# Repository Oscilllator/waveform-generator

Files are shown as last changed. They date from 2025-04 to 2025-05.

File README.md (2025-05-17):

# Why does it exist

The purpose of this waveform generator is to give your computer the ability to make waves. It should be thought of as a waveform interface for your computer, like a network interface or an audio interface. The computer streams waveforms continuously to the generator, the generator itself has no memory.
I created this because I don't like the software interface to any other waveform generator I have used.

You use it like this:
```python
import numpy as np
import awglib
awg = awglib.awg()
samples = np.sin(np.linspace(0, 2 * np.pi, 1000))
awg.send_volts(samples)
```

You can simply stream samples to it, or gate the sending of the samples on a trigger input. It also has two digital outputs which are embedded in the sample stream. You can use them like this:

```python
samples = np.sin(np.linspace(0, 2 * np.pi, 1000))
d0 = samples > 0.8
d1 = samples < -0.5
awg.send_volts(samples, digital=[d0, d1])
```

Which then would look like this:
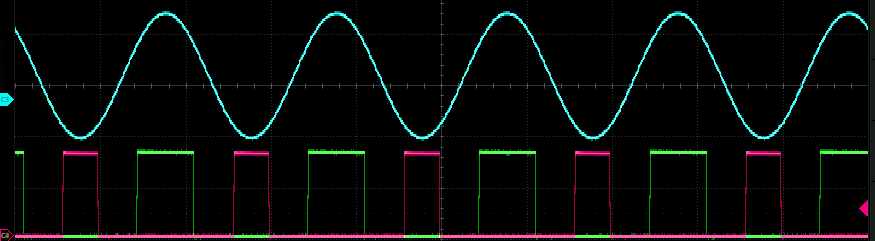
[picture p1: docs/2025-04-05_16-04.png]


This is useful for triggering your scope or other instruments.

## Specifications
| Parameter | Value |
|---|---|
| Samples rate | 10 MSa/s |
| Rise/fall time | 50 ns |
| Max output current  | 600 mA |
| Resolution | 14 bit |
| Digital outputs | 2 |

The device also has a 16 bit digital output bus for debugging the fpga, and 8 LED's. The digital outputs come straight from the FPGA and so have no drive strength to speak of. You won't blow up the FPGA if you 50R terminate them, though.

It looks like this:

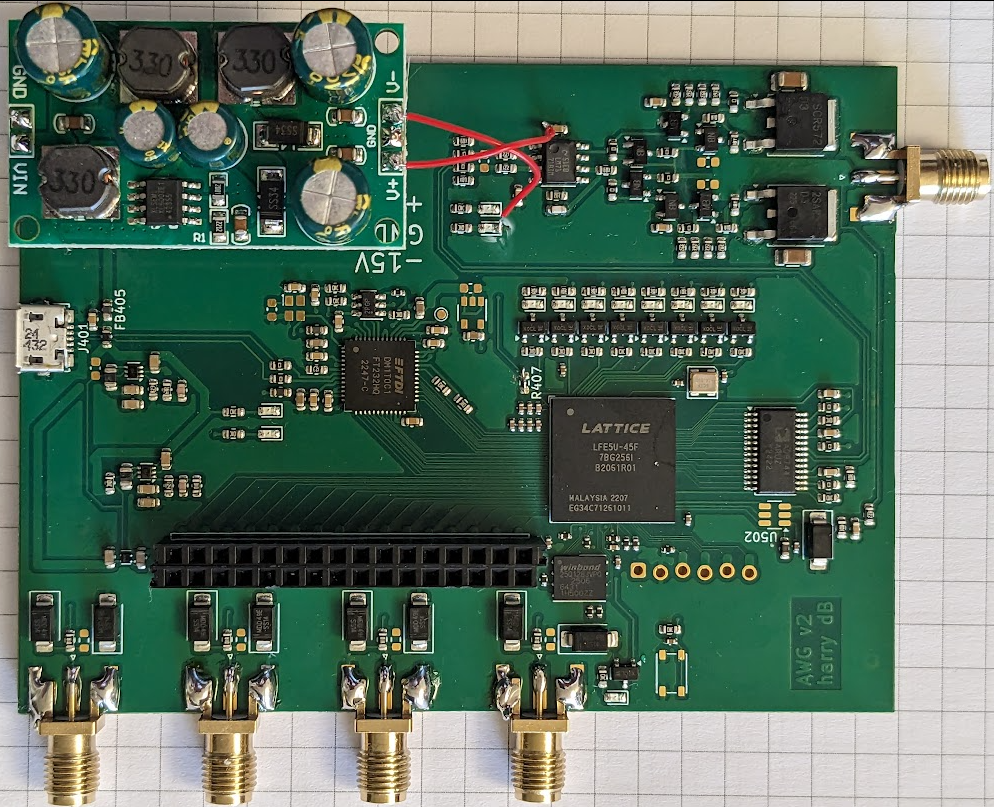
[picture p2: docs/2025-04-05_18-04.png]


## Examples

### Scrolling text

This example is `examples/scrolling_text.py` and demonstrates some of the benefits of having a streaming setup - there is a lot of memory on your main computer as compared to any reasonable waveform generator.

This whole gif is one single waveform of about ~500MB over the wire. Several passes are made over the text, one for each letter section. The persistence of vision within the oscilloscope stitches them together, producing whole letters. Once the whole text has been emitted the waveform is then re-emitted with the embedded digital trigger pulse sent with a slightly different time delay. This is easily done by simply concatenating the waveform to itself many times, attaching a shifted version of the trigger array each time. This wastes a lot of memory but was trivial to implement.

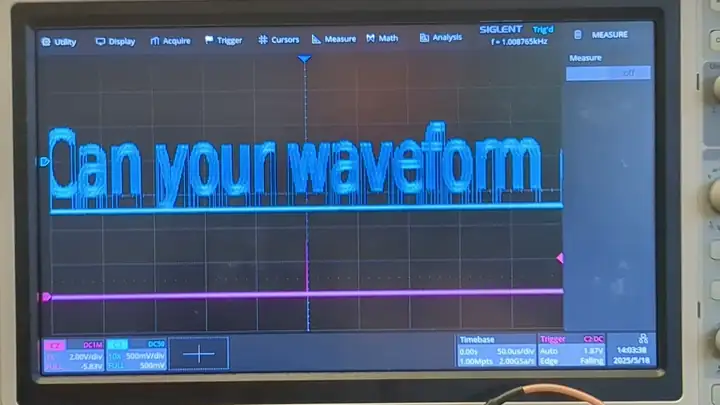
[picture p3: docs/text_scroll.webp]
demo


## Setup
### From a new computer
#### Udev rules
The USB chip is a FT232, but I have programmed it to have a custom Vid and Pid, so that the linux kernel doesn't grab it.

This script sets up the udev rules so the device can be opened without root:

```./ft/setup.sh```
#### Python library
I install it like this from the root directory of the repository:

```pip install -e .```

That way the library is loaded from the repository on startup rather than being copied to an install directory. Ask your favourite AI what's right for you.

### From a bare PCB
The EEPROM of the FT2332 needs to be programmed so that it will output in synchronous FIFO mode, and so that the default vendor ID and product ID is changed, preventing the linux kernel from recognising it.

```./program_eeprom.sh```

## Repository contents
This repository contains the kicad files, RTL, and API to operate a waveform generator.

### Hardware
I got the PCB's assembled with JLCPCB's 6 layer service with plated over vias, to make the routing of the FPGA BGA package easy.
The device uses an FT232 as a USB->FIFO adapter, that currently streams exclusively in the PC->FT232 direction. Use of the device in this mode requires flashing the eeprom, for which a utility is also included.

### RTL
The Flow of information is as follows:

PC -> FT232 -> ECP5 FPGA -> AD9744 DAC -> Amplifier

The RTL for the fpga is provided, which uses the excellent repository [here](https://github.com/WangXuan95/FPGA-ftdi245fifo/tree/main?tab=readme-ov-file#cn) to interface with the FT232. The AD9744 has a simple parallel interface, so that also makes things easy.

The simulation can be run as a unit test with `./run_tests.sh`

### API
The waveform generator is interfaces with in python, though I may [port it to C](https://harrydb.com/Continuous-waveforms) at some point.

### Bringup notes

This device was designed as a series of sub-boards. It started as a [Colorlight DAC](https://harrydb.com/20240902-A-good-waveform-generator) dev board and the [amplifier stage](https://harrydb.com/20250103-awg-buffer-bringup). These were then merged into a [Single PCB](https://harrydb.com/20250403-AWG-2-bringup). There are [various other notes](https://harrydb.com/#waveform-generator) on my lab notes page that detail other parts of the design process.

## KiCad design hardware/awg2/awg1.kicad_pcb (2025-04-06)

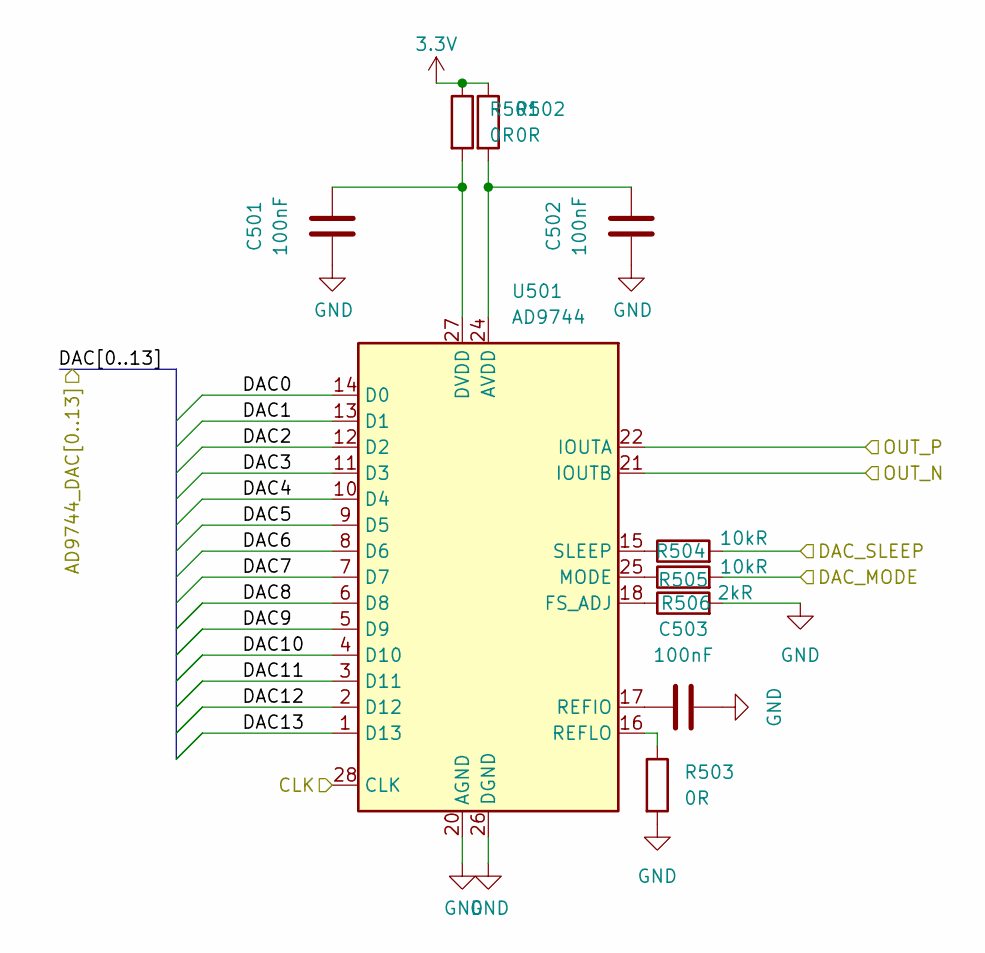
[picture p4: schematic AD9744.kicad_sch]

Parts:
C501, C502, C503: 100nF; R_0603_1608Metric; LCSC C1634
R501, R502: 0R; R_0603_1608Metric
R503: 0R; R_0603_1608Metric; LCSC C22787
R504, R505: 10kR; R_0603_1608Metric; LCSC C22787
R506: 2kR; R_0603_1608Metric; LCSC C22787
U501: AD9744; TSSOP-28_4.4x9.7mm_P0.65mm

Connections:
3.3V: R501.1, R502.1; also elsewhere on the board
/AD9744/CLK: U501.28 (CLK); also elsewhere on the board
/AD9744/DAC0: U501.14 (D0); also elsewhere on the board
/AD9744/DAC1: U501.13 (D1); also elsewhere on the board
/AD9744/DAC2: U501.12 (D2); also elsewhere on the board
/AD9744/DAC3: U501.11 (D3); also elsewhere on the board
/AD9744/DAC4: U501.10 (D4); also elsewhere on the board
/AD9744/DAC5: U501.9 (D5); also elsewhere on the board
/AD9744/DAC6: U501.8 (D6); also elsewhere on the board
/AD9744/DAC7: U501.7 (D7); also elsewhere on the board
/AD9744/DAC8: U501.6 (D8); also elsewhere on the board
/AD9744/DAC9: U501.5 (D9); also elsewhere on the board
/AD9744/DAC10: U501.4 (D10); also elsewhere on the board
/AD9744/DAC11: U501.3 (D11); also elsewhere on the board
/AD9744/DAC12: U501.2 (D12); also elsewhere on the board
/AD9744/DAC13: U501.1 (D13); also elsewhere on the board
/AD9744/DAC_MODE: R505.2; also elsewhere on the board
/AD9744/DAC_SLEEP: R504.2; also elsewhere on the board
/AD9744/OUT_N: U501.21 (IOUTB); also elsewhere on the board
/AD9744/OUT_P: U501.22 (IOUTA); also elsewhere on the board
GND: C501.1, C502.1, C503.1, R503.2, R506.2, U501.20 (AGND), U501.26 (DGND); also elsewhere on the board
unnamed: C502.2, R502.2, U501.24 (AVDD)
unnamed: C501.2, R501.2, U501.27 (DVDD)
unnamed: R506.1, U501.18 (FS_ADJ)
unnamed: R505.1, U501.25 (MODE)
unnamed: C503.2, U501.17 (REFIO)
unnamed: R503.1, U501.16 (REFLO)
unnamed: R504.1, U501.15 (SLEEP)

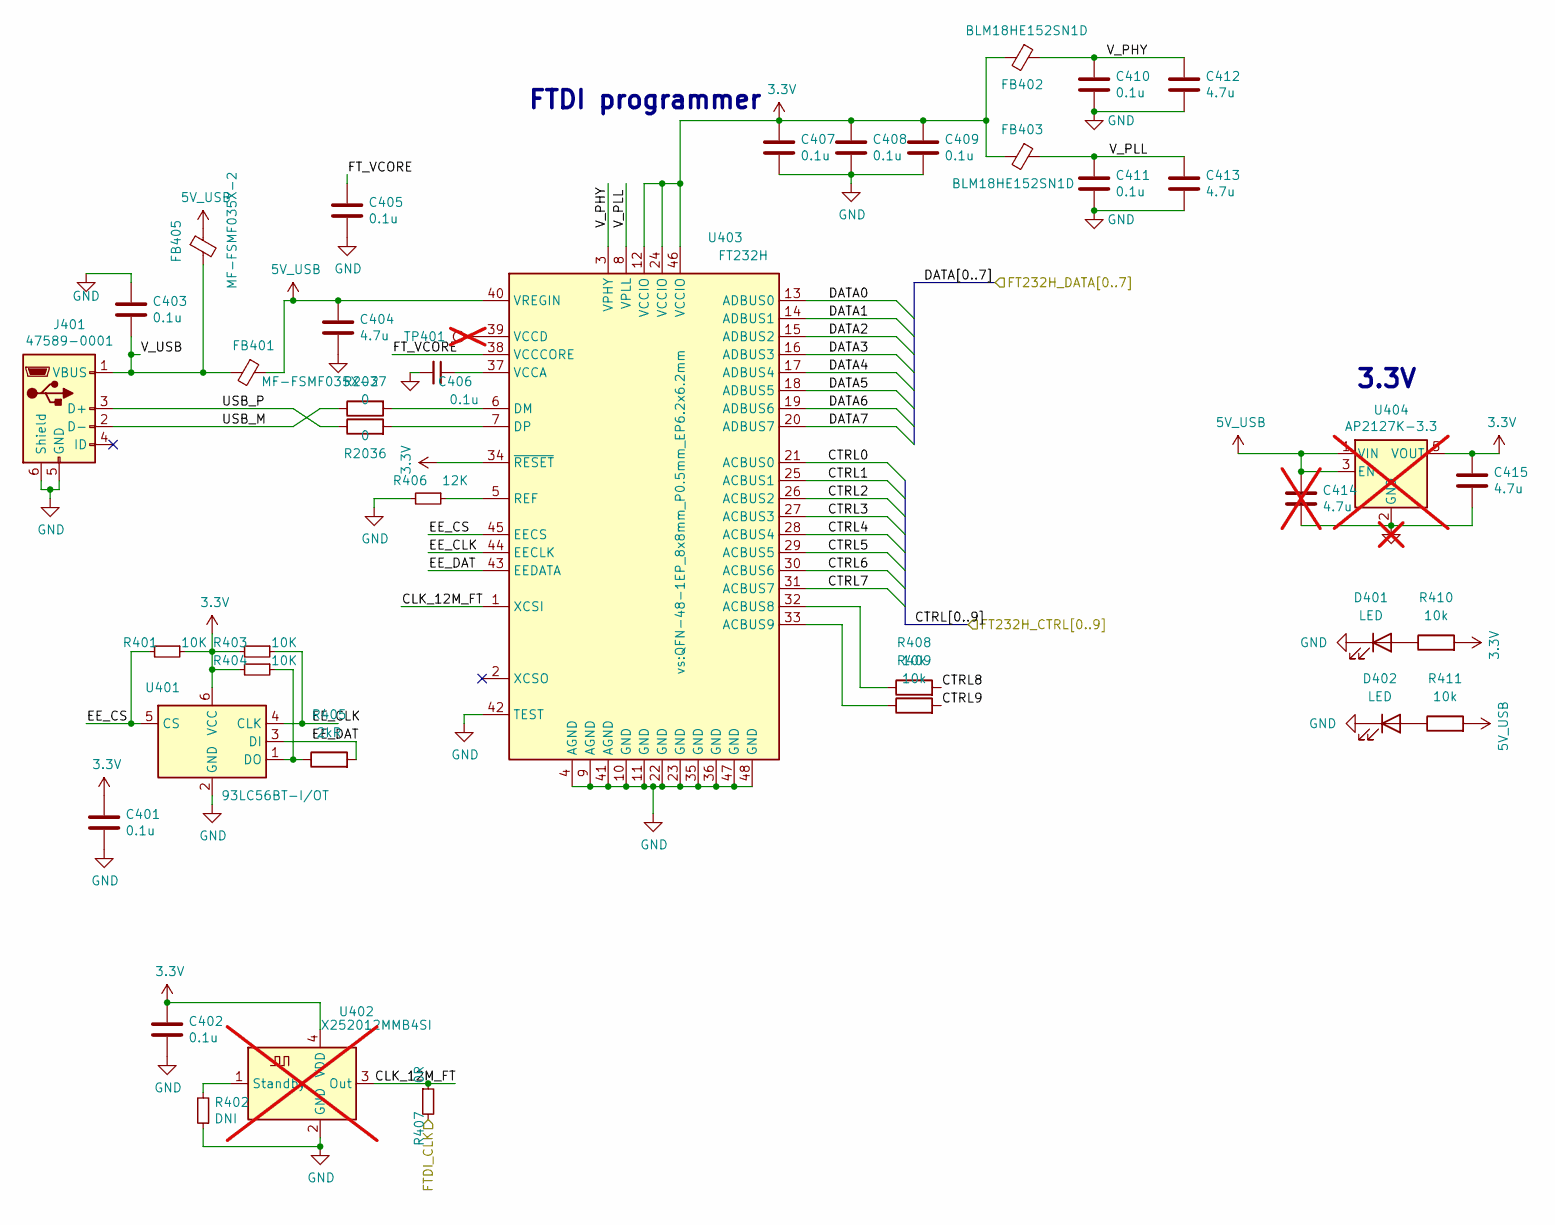
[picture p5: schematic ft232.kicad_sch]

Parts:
C401, C402, C403, C405, C406, C407, C408, C409, C410, C411: 0.1u; C_0603_1608Metric
C404, C412, C413, C415: 4.7u; C_0603_1608Metric
C414: 4.7u; C_0603_1608Metric; not fitted
D401, D402: LED; D_0603_1608Metric; LCSC C2286
FB401, FB405: MF-FSMF035X-2; L_0603_1608Metric
FB402, FB403: BLM18HE152SN1D; L_0603_1608Metric
J401: 47589-0001; USB_Micro-B_Molex_47346-0001
R401, R403, R404: 10K; R_0603_1608Metric
R402: DNI; R_0603_1608Metric
R405: 2kR; R_0402_1005Metric
R406: 12K; R_0603_1608Metric
R407: 0R; R_0603_1608Metric
R408, R409, R410, R411: 10k; R_0603_1608Metric; LCSC C25804
R2036, R2037: 0; R_0603_1608Metric; LCSC C21189
TP401: TestPoint; TestPoint_Pad_D1.0mm; not fitted
U401: 93LC56BT-I/OT; SOT-23-6
U402: X252012MMB4SI; Oscillator_SMD_Abracon_ASDMB-4Pin_2.5x2.0mm; not fitted
U403: FT232H; QFN-48-1EP_8x8mm_P0.5mm_EP6.2x6.2mm
U404: AP2127K-3.3; SOT-23-5; not fitted

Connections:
3.3V: C401.1, C402.1, C407.1, C408.1, C409.1, C415.1, FB402.2, FB403.2, R401.1, R403.2, R404.2, R410.2, U401.6 (VCC), U402.4 (VDD), U403.12 (VCCIO), U403.24 (VCCIO), U403.34 (~RESET), U403.46 (VCCIO), U404.5 (VOUT); also elsewhere on the board
5V_USB: C404.1, C414.1, FB401.1, FB405.1, R411.2, U403.40 (VREGIN), U404.1 (VIN), U404.3 (EN); also elsewhere on the board
/fpga/CTRL0: U403.21 (ACBUS0); also elsewhere on the board
/fpga/CTRL1: U403.25 (ACBUS1); also elsewhere on the board
/fpga/CTRL2: U403.26 (ACBUS2); also elsewhere on the board
/fpga/CTRL3: U403.27 (ACBUS3); also elsewhere on the board
/fpga/CTRL4: U403.28 (ACBUS4); also elsewhere on the board
/fpga/CTRL5: U403.29 (ACBUS5); also elsewhere on the board
/fpga/CTRL6: U403.30 (ACBUS6); also elsewhere on the board
/fpga/CTRL7: U403.31 (ACBUS7); also elsewhere on the board
/fpga/CTRL8: R408.2; also elsewhere on the board
/fpga/CTRL9: R409.2; also elsewhere on the board
/fpga/DATA0: U403.13 (ADBUS0); also elsewhere on the board
/fpga/DATA1: U403.14 (ADBUS1); also elsewhere on the board
/fpga/DATA2: U403.15 (ADBUS2); also elsewhere on the board
/fpga/DATA3: U403.16 (ADBUS3); also elsewhere on the board
/fpga/DATA4: U403.17 (ADBUS4); also elsewhere on the board
/fpga/DATA5: U403.18 (ADBUS5); also elsewhere on the board
/fpga/DATA6: U403.19 (ADBUS6); also elsewhere on the board
/fpga/DATA7: U403.20 (ADBUS7); also elsewhere on the board
/fpga/FTDI_CLK: R407.2; also elsewhere on the board
/ft232/CLK_12M_FT: R407.1, U402.3 (Out), U403.1 (XCSI)
/ft232/EE_CLK: R403.1, U401.4 (CLK), U403.44 (EECLK)
/ft232/EE_CS: R401.2, U401.5 (CS), U403.45 (EECS)
/ft232/EE_DAT: R405.2, U401.3 (DI), U403.43 (EEDATA)
/ft232/FT_VCORE: C405.1, U403.38 (VCCCORE)
/ft232/USB_M: J401.2 (D-), R2036.1
/ft232/USB_P: J401.3 (D+), R2037.1
/ft232/V_PHY: C410.1, C412.1, FB402.1, U403.3 (VPHY)
/ft232/V_PLL: C411.1, C413.1, FB403.1, U403.8 (VPLL)
/ft232/V_USB: C403.2, FB401.2, FB405.2, J401.1 (VBUS)
GND: C401.2, C402.2, C403.1, C404.2, C405.2, C406.2, C407.2, C408.2, C409.2, C410.2, C411.2, C412.2, C413.2, C414.2, C415.2, D401.1 (K), D402.1 (K), J401.5 (GND), J401.6 (Shield), R402.1, R406.2, U401.2 (GND), U402.2 (GND), U403.4 (AGND), U403.9 (AGND), U403.10 (GND), U403.11 (GND), U403.22 (GND), U403.23 (GND), U403.35 (GND), U403.36 (GND), U403.41 (AGND), U403.42 (TEST), U403.47 (GND), U403.48 (GND), U404.2 (GND); also elsewhere on the board
unnamed: D401.2 (A), R410.1
unnamed: D402.2 (A), R411.1
unnamed: R404.1, R405.1, U401.1 (DO)
unnamed: R402.2, U402.1 (Standby)
unnamed: R408.1, U403.32 (ACBUS8)
unnamed: R409.1, U403.33 (ACBUS9)
unnamed: R2036.2, U403.6 (DM)
unnamed: R2037.2, U403.7 (DP)
unnamed: R406.1, U403.5 (REF)
unnamed: C406.1, U403.37 (VCCA)
unnamed: TP401.1, U403.39 (VCCD)

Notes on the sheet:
3.3V
FTDI programmer

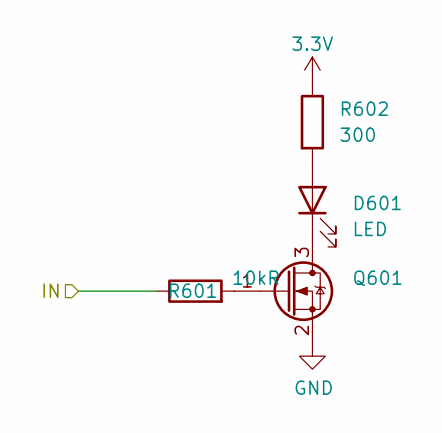
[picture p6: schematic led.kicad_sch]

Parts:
D601: LED; D_0603_1608Metric
Q601: Q_NMOS_Depletion_GSD; SOT-23; LCSC C20917
R601: 10kR; R_0603_1608Metric; LCSC C22787
R602: 300; R_0603_1608Metric_Pad0.98x0.95mm_HandSolder

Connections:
3.3V: R602.1; also elsewhere on the board
/lED0: R601.1; also elsewhere on the board
GND: Q601.2 (S); also elsewhere on the board
unnamed: D601.2 (A), R602.2
unnamed: D601.1 (K), Q601.3 (D)
unnamed: Q601.1 (G), R601.2

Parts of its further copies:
D701, D801, D901, D1001, D1101, D1201, D1301: LED; D_0603_1608Metric
Q701, Q801, Q901, Q1001, Q1101, Q1201, Q1301: Q_NMOS_Depletion_GSD; SOT-23; LCSC C20917
R701, R801, R901, R1001, R1101, R1201, R1301: 10kR; R_0603_1608Metric; LCSC C22787
R702, R802, R902, R1002, R1102, R1202, R1302: 300; R_0603_1608Metric_Pad0.98x0.95mm_HandSolder

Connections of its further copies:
3.3V: R702.1, R802.1, R902.1, R1002.1, R1102.1, R1202.1, R1302.1; also elsewhere on the board
/lED1: R701.1; also elsewhere on the board
/lED2: R801.1; also elsewhere on the board
/lED3: R901.1; also elsewhere on the board
/lED4: R1001.1; also elsewhere on the board
/lED5: R1101.1; also elsewhere on the board
/lED6: R1201.1; also elsewhere on the board
/lED7: R1301.1; also elsewhere on the board
GND: Q701.2 (S), Q801.2 (S), Q901.2 (S), Q1001.2 (S), Q1101.2 (S), Q1201.2 (S), Q1301.2 (S); also elsewhere on the board
unnamed: D701.2 (A), R702.2
unnamed: D701.1 (K), Q701.3 (D)
unnamed: D801.2 (A), R802.2
unnamed: D801.1 (K), Q801.3 (D)
unnamed: D901.2 (A), R902.2
unnamed: D901.1 (K), Q901.3 (D)
unnamed: D1001.2 (A), R1002.2
unnamed: D1001.1 (K), Q1001.3 (D)
unnamed: D1101.2 (A), R1102.2
unnamed: D1101.1 (K), Q1101.3 (D)
unnamed: D1201.2 (A), R1202.2
unnamed: D1201.1 (K), Q1201.3 (D)
unnamed: D1301.2 (A), R1302.2
unnamed: D1301.1 (K), Q1301.3 (D)
unnamed: Q701.1 (G), R701.2
unnamed: Q801.1 (G), R801.2
unnamed: Q901.1 (G), R901.2
unnamed: Q1001.1 (G), R1001.2
unnamed: Q1101.1 (G), R1101.2
unnamed: Q1201.1 (G), R1201.2
unnamed: Q1301.1 (G), R1301.2

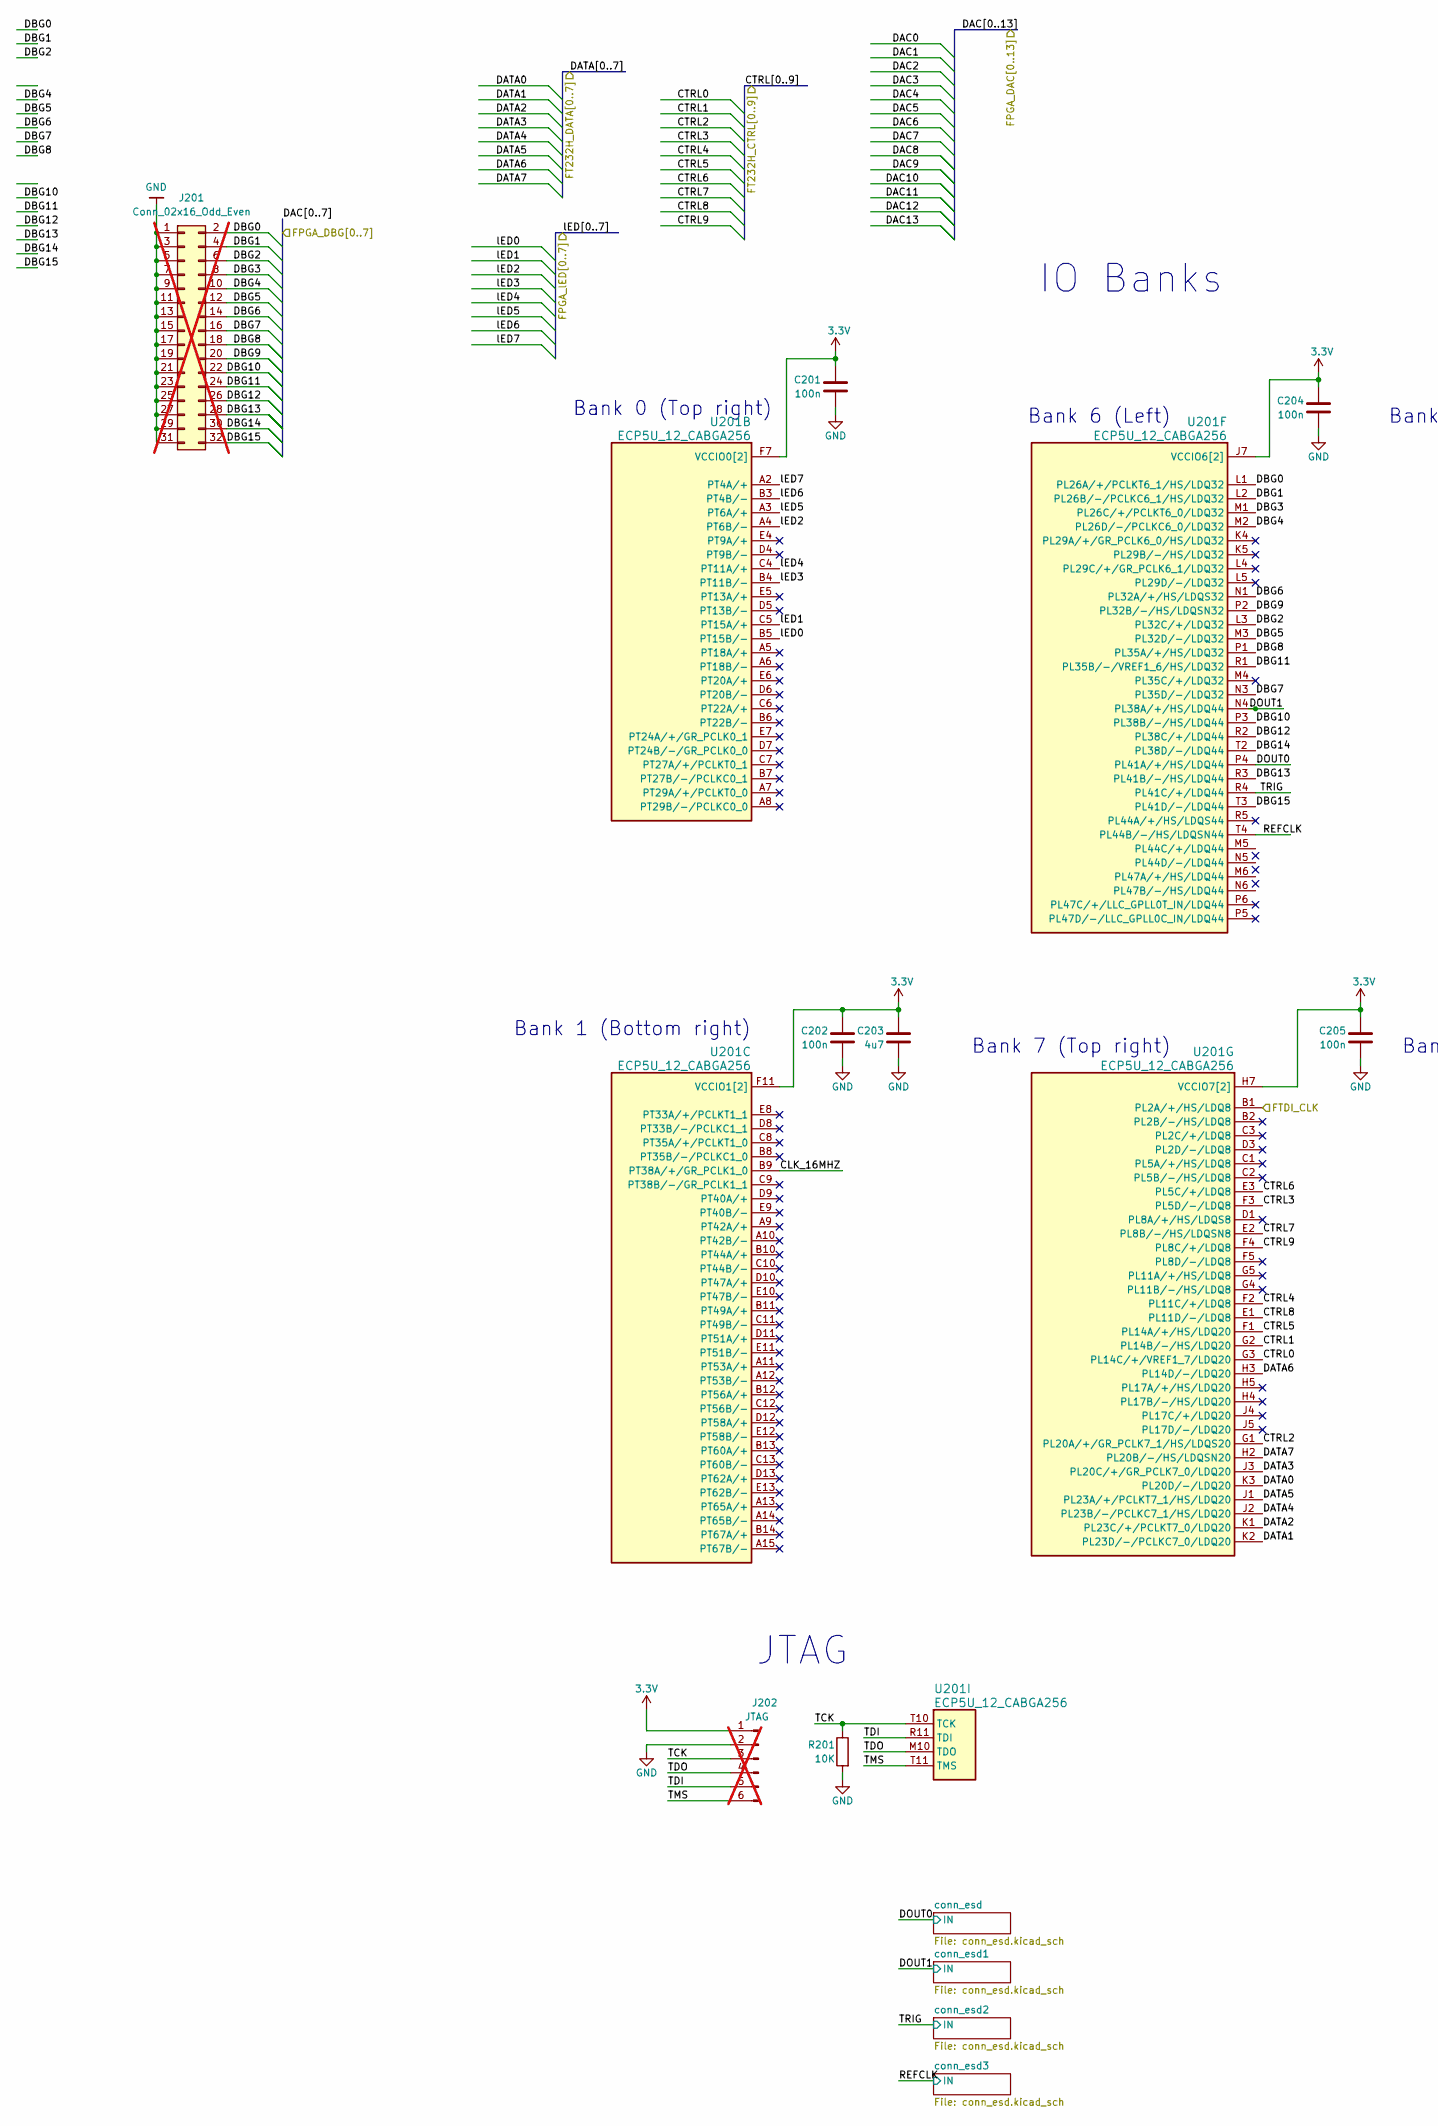
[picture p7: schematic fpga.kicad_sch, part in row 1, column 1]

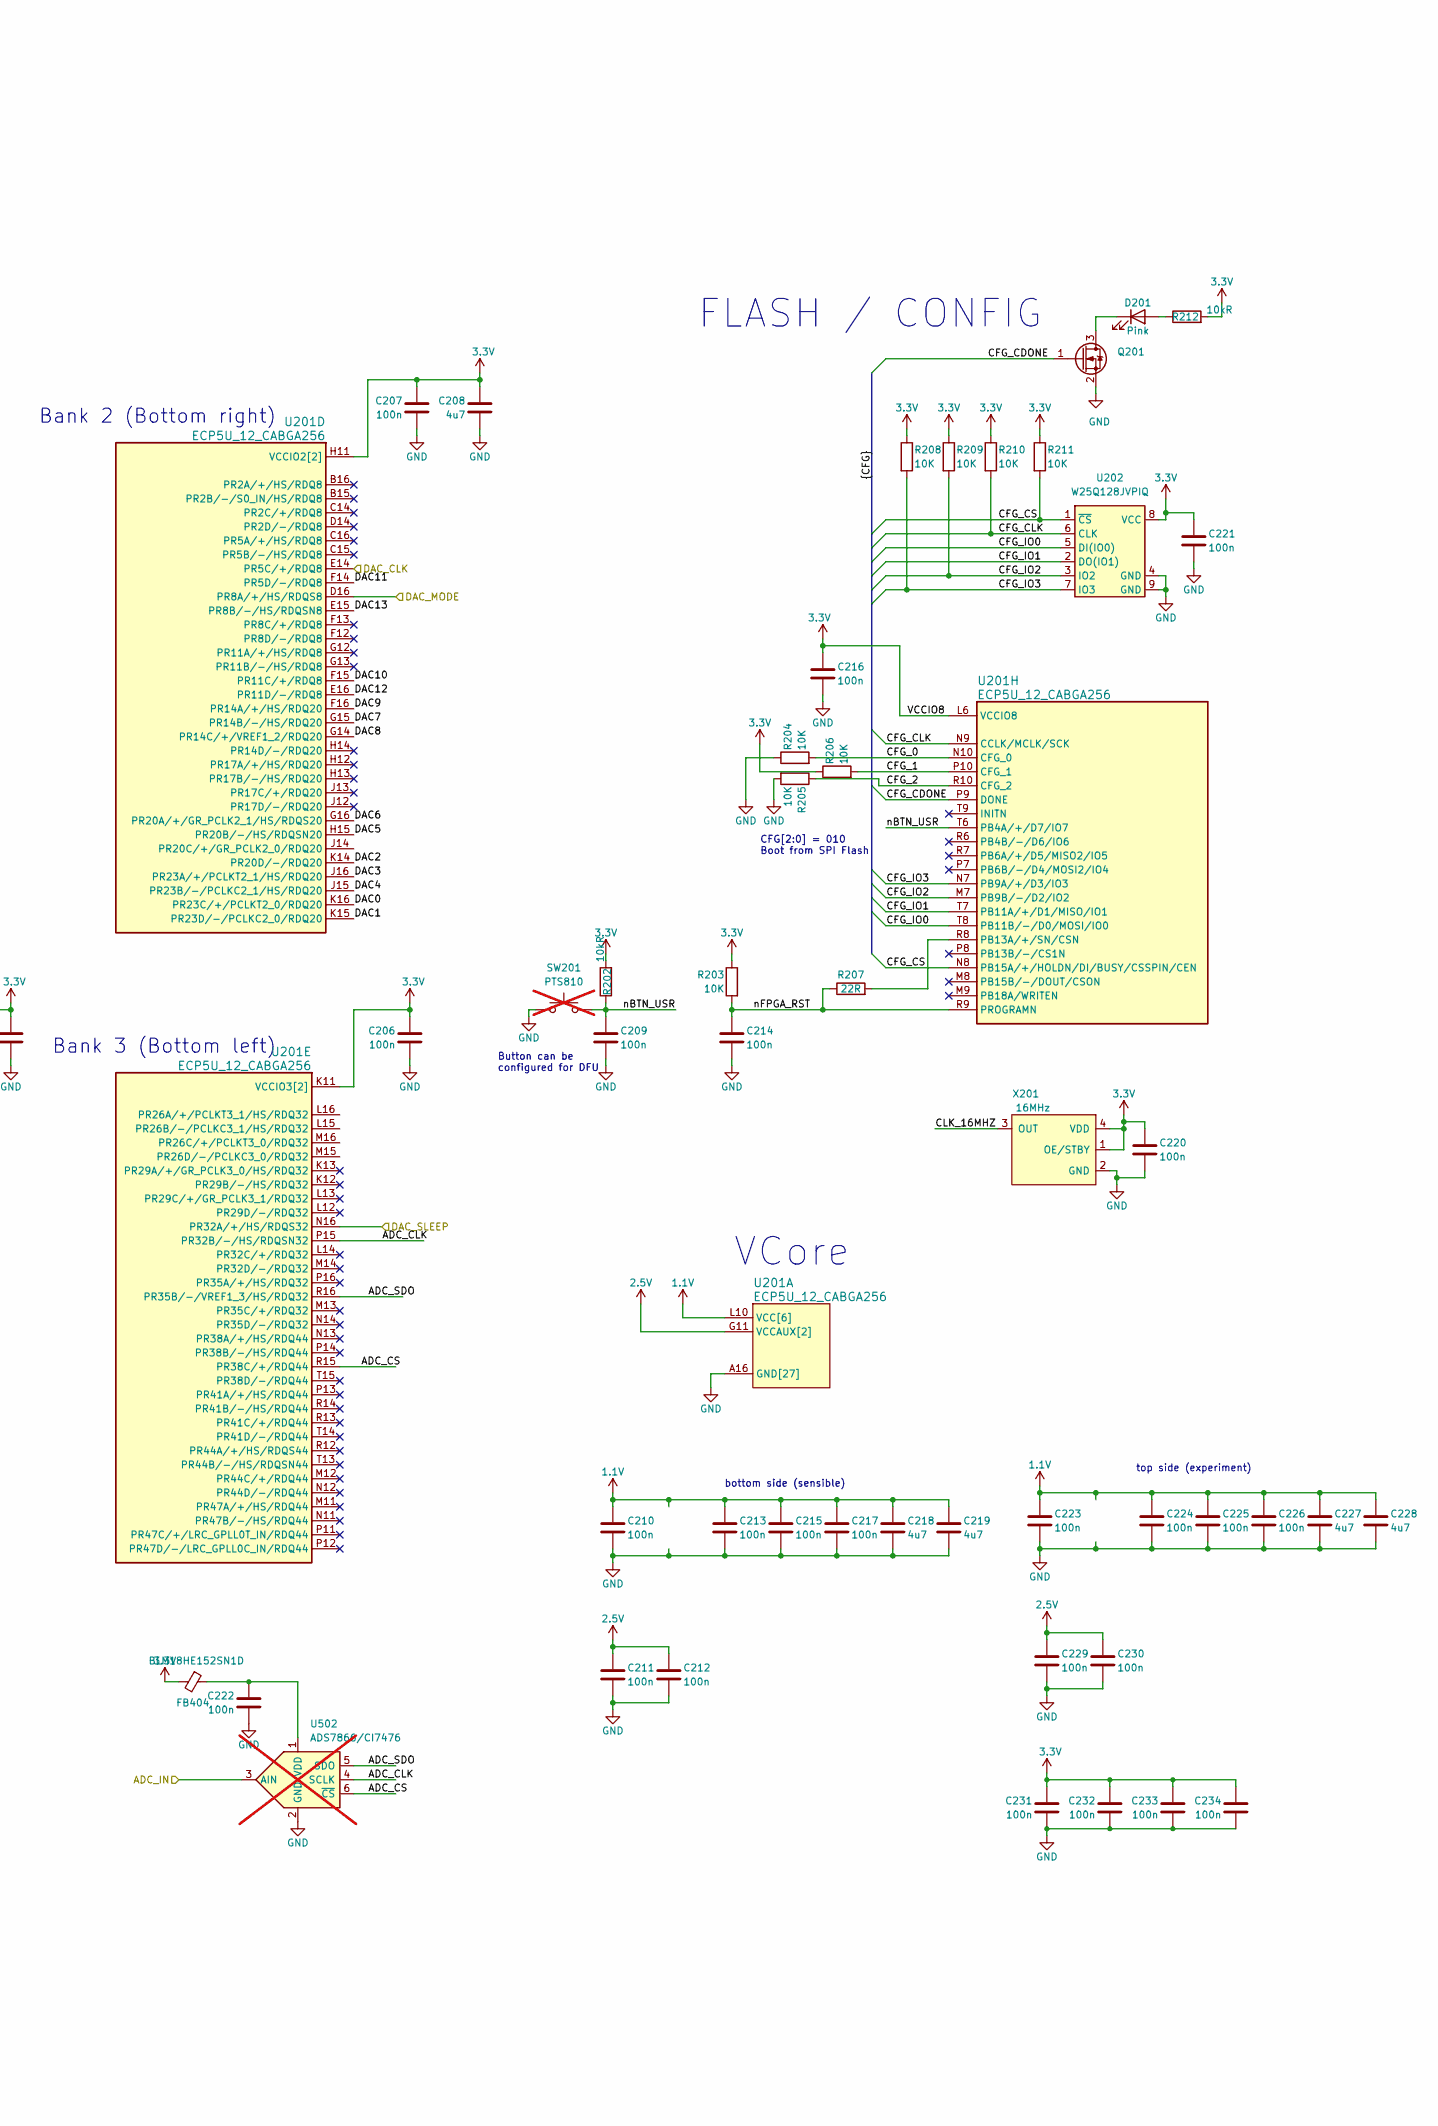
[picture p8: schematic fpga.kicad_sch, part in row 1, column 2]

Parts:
C201, C202, C204, C205, C206, C207, C210, C211, C212, C213, C215, C216, C217, C220, C221, C222, C223, C224, C225, C226, C229, C230, C231, C232, C233, C234: 100n; C_0402_1005Metric; MPN CC0402KRX7R7BB104; LCSC C327009
C203, C208, C218, C219, C227, C228: 4u7; C_0402_1005Metric; MPN CC0402KRX5R6BB475; LCSC C326586
C209, C214: 100n; C_0402_1005Metric; MPN CC0402KRX7R7BB104
D201: Pink; LED_0603_1608Metric; MPN OSK40603C1E; LCSC C268294
FB404: BLM18HE152SN1D; L_0603_1608Metric
J201: Conn_02x16_Odd_Even; PinHeader_2x16_P2.54mm_Vertical; not fitted
J202: JTAG; STM_6_PIN_THT_Staggered; not fitted
Q201: Q_NMOS_Depletion_GSD; SOT-23; LCSC C20917
R201, R203, R204, R205, R206, R208, R209, R210, R211: 10K; R_0402_1005Metric; MPN RC0402JR-0710KL; LCSC C60489
R202, R212: 10kR; R_0603_1608Metric; LCSC C22787
R207: 22R; R_0402_1005Metric; MPN RC0402JR-0722RL
SW201: PTS810; SW_SPST_PTS810; MPN PTS810 SJM 250 SMTR LFS; LCSC C116501; not fitted
U201: ECP5U_12_CABGA256; BGA-256_14.0x14.0mm_Layout16x16_P0.8mm_Ball0.45mm_Pad0.32mm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; MPN LFE5U12F8BG256C
U202: W25Q128JVPIQ; WSON-8-1EP_6x5mm_P1.27mm_EP3.4x4.3mm; MPN W25Q128JVPIQ; LCSC C190862
U502: ADS7866/CI7476; TSOT-23-6; not fitted
X201: 16MHz; CDFN_3.2x2.5mm_XO; MPN DSC6101CI2A-016.0000

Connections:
1.1V: C210.1, C213.1, C215.1, C217.1, C218.1, C219.1, C223.1, C224.1, C225.1, C226.1, C227.1, C228.1, U201.G6 (VCC[6]), U201.G7 (VCC[6]), U201.G9 (VCC[6]), U201.L8 (VCC[6]), U201.L9 (VCC[6]), U201.L10 (VCC[6]); also elsewhere on the board
2.5V: C211.1, C212.1, C229.1, C230.1, U201.G11 (VCCAUX[2]), U201.L7 (VCCAUX[2]); also elsewhere on the board
3.3V: C201.1, C202.1, C203.1, C204.1, C205.1, C206.1, C207.1, C208.1, C216.1, C220.1, C221.1, C231.1, C232.1, C233.1, C234.1, FB404.2, J202.1, R202.2, R203.1, R206.1, R208.1, R209.1, R210.1, R211.1, R212.2, U201.F6 (VCCIO0[2]), U201.F7 (VCCIO0[2]), U201.F10 (VCCIO1[2]), U201.F11 (VCCIO1[2]), U201.H6 (VCCIO7[2]), U201.H7 (VCCIO7[2]), U201.H11 (VCCIO2[2]), U201.J6 (VCCIO6[2]), U201.J7 (VCCIO6[2]), U201.J11 (VCCIO2[2]), U201.K11 (VCCIO3[2]), U201.L6 (VCCIO8), U201.L11 (VCCIO3[2]), U202.8 (VCC), X201.1 (OE/STBY), X201.4 (VDD); also elsewhere on the board
/AD9744/CLK: U201.E14 (PR5C/+/RDQ8); also elsewhere on the board
/AD9744/DAC0: U201.K16 (PR23C/+/PCLKT2_0/RDQ20); also elsewhere on the board
/AD9744/DAC1: U201.K15 (PR23D/-/PCLKC2_0/RDQ20); also elsewhere on the board
/AD9744/DAC2: U201.K14 (PR20D/-/RDQ20); also elsewhere on the board
/AD9744/DAC3: U201.J16 (PR23A/+/PCLKT2_1/HS/RDQ20); also elsewhere on the board
/AD9744/DAC4: U201.J15 (PR23B/-/PCLKC2_1/HS/RDQ20); also elsewhere on the board
/AD9744/DAC5: U201.H15 (PR20B/-/HS/RDQSN20); also elsewhere on the board
/AD9744/DAC6: U201.G16 (PR20A/+/GR_PCLK2_1/HS/RDQS20); also elsewhere on the board
/AD9744/DAC7: U201.G15 (PR14B/-/HS/RDQ20); also elsewhere on the board
/AD9744/DAC8: U201.G14 (PR14C/+/VREF1_2/RDQ20); also elsewhere on the board
/AD9744/DAC9: U201.F16 (PR14A/+/HS/RDQ20); also elsewhere on the board
/AD9744/DAC10: U201.F15 (PR11C/+/RDQ8); also elsewhere on the board
/AD9744/DAC11: U201.F14 (PR5D/-/RDQ8); also elsewhere on the board
/AD9744/DAC12: U201.E16 (PR11D/-/RDQ8); also elsewhere on the board
/AD9744/DAC13: U201.E15 (PR8B/-/HS/RDQSN8); also elsewhere on the board
/AD9744/DAC_MODE: U201.D16 (PR8A/+/HS/RDQS8); also elsewhere on the board
/AD9744/DAC_SLEEP: U201.N16 (PR32A/+/HS/RDQS32); also elsewhere on the board
/awg_amp/OUT_SLOW: U502.3 (AIN); also elsewhere on the board
/fpga/ADC_CLK: U201.P15 (PR32B/-/HS/RDQSN32), U502.4 (SCLK)
/fpga/ADC_CS: U201.R15 (PR38C/+/RDQ44), U502.6 (~CS)
/fpga/ADC_SDO: U201.R16 (PR35B/-/VREF1_3/HS/RDQ32), U502.5 (SDO)
/fpga/CFG_0: R204.2, U201.N10 (CFG_0)
/fpga/CFG_1: R206.2, U201.P10 (CFG_1)
/fpga/CFG_2: R205.1, U201.R10 (CFG_2)
/fpga/CFG_CDONE: Q201.1 (G), U201.P9 (DONE)
/fpga/CFG_CLK: R210.2, U201.N9 (CCLK/MCLK/SCK), U202.6 (CLK)
/fpga/CFG_CS: R211.2, U201.N8 (PB15A/+/HOLDN/DI/BUSY/CSSPIN/CEN), U202.1 (~CS)
/fpga/CFG_IO0: U201.T8 (PB11B/-/D0/MOSI/IO0), U202.5 (DI(IO0))
/fpga/CFG_IO1: U201.T7 (PB11A/+/D1/MISO/IO1), U202.2 (DO(IO1))
/fpga/CFG_IO2: R209.2, U201.M7 (PB9B/-/D2/IO2), U202.3 (IO2)
/fpga/CFG_IO3: R208.2, U201.N7 (PB9A/+/D3/IO3), U202.7 (IO3)
/fpga/CLK_16MHZ: U201.B9 (PT38A/+/GR_PCLK1_0), X201.3 (OUT)
/fpga/CTRL0: U201.G3 (PL14C/+/VREF1_7/LDQ20); also elsewhere on the board
/fpga/CTRL1: U201.G2 (PL14B/-/HS/LDQ20); also elsewhere on the board
/fpga/CTRL2: U201.G1 (PL20A/+/GR_PCLK7_1/HS/LDQS20); also elsewhere on the board
/fpga/CTRL3: U201.F3 (PL5D/-/LDQ8); also elsewhere on the board
/fpga/CTRL4: U201.F2 (PL11C/+/LDQ8); also elsewhere on the board
/fpga/CTRL5: U201.F1 (PL14A/+/HS/LDQ20); also elsewhere on the board
/fpga/CTRL6: U201.E3 (PL5C/+/LDQ8); also elsewhere on the board
/fpga/CTRL7: U201.E2 (PL8B/-/HS/LDQSN8); also elsewhere on the board
/fpga/CTRL8: U201.E1 (PL11D/-/LDQ8); also elsewhere on the board
/fpga/CTRL9: U201.F4 (PL8C/+/LDQ8); also elsewhere on the board
/fpga/DATA0: U201.K3 (PL20D/-/LDQ20); also elsewhere on the board
/fpga/DATA1: U201.K2 (PL23D/-/PCLKC7_0/LDQ20); also elsewhere on the board
/fpga/DATA2: U201.K1 (PL23C/+/PCLKT7_0/LDQ20); also elsewhere on the board
/fpga/DATA3: U201.J3 (PL20C/+/GR_PCLK7_0/LDQ20); also elsewhere on the board
/fpga/DATA4: U201.J2 (PL23B/-/PCLKC7_1/HS/LDQ20); also elsewhere on the board
/fpga/DATA5: U201.J1 (PL23A/+/PCLKT7_1/HS/LDQ20); also elsewhere on the board
/fpga/DATA6: U201.H3 (PL14D/-/LDQ20); also elsewhere on the board
/fpga/DATA7: U201.H2 (PL20B/-/HS/LDQSN20); also elsewhere on the board
/fpga/DBG0: J201.2, U201.L1 (PL26A/+/PCLKT6_1/HS/LDQ32)
/fpga/DBG1: J201.4, U201.L2 (PL26B/-/PCLKC6_1/HS/LDQ32)
/fpga/DBG2: J201.6, U201.L3 (PL32C/+/LDQ32)
/fpga/DBG3: J201.8, U201.M1 (PL26C/+/PCLKT6_0/LDQ32)
/fpga/DBG4: J201.10, U201.M2 (PL26D/-/PCLKC6_0/LDQ32)
/fpga/DBG5: J201.12, U201.M3 (PL32D/-/LDQ32)
/fpga/DBG6: J201.14, U201.N1 (PL32A/+/HS/LDQS32)
/fpga/DBG7: J201.16, U201.N3 (PL35D/-/LDQ32)
/fpga/DBG8: J201.18, U201.P1 (PL35A/+/HS/LDQ32)
/fpga/DBG9: J201.20, U201.P2 (PL32B/-/HS/LDQSN32)
/fpga/DBG10: J201.22, U201.P3 (PL38B/-/HS/LDQ44)
/fpga/DBG11: J201.24, U201.R1 (PL35B/-/VREF1_6/HS/LDQ32)
/fpga/DBG12: J201.26, U201.R2 (PL38C/+/LDQ44)
/fpga/DBG13: J201.28, U201.R3 (PL41B/-/HS/LDQ44)
/fpga/DBG14: J201.30, U201.T2 (PL38D/-/LDQ44)
/fpga/DBG15: J201.32, U201.T3 (PL41D/-/LDQ44)
/fpga/DOUT0: U201.P4 (PL41A/+/HS/LDQ44); also elsewhere on the board
/fpga/DOUT1: U201.N4 (PL38A/+/HS/LDQ44); also elsewhere on the board
/fpga/FTDI_CLK: U201.B1 (PL2A/+/HS/LDQ8); also elsewhere on the board
/fpga/REFCLK: U201.T4 (PL44B/-/HS/LDQSN44); also elsewhere on the board
/fpga/TCK: J202.3, R201.1, U201.T10 (TCK)
/fpga/TDI: J202.5, U201.R11 (TDI)
/fpga/TDO: J202.4, U201.M10 (TDO)
/fpga/TMS: J202.6, U201.T11 (TMS)
/fpga/TRIG: U201.R4 (PL41C/+/LDQ44); also elsewhere on the board
/fpga/nBTN_USR: C209.1, R202.1, SW201.2, U201.T6 (PB4A/+/D7/IO7)
/fpga/nFPGA_RST: C214.1, R203.2, R207.1, U201.R9 (PROGRAMN)
/lED0: U201.B5 (PT15B/-); also elsewhere on the board
/lED1: U201.C5 (PT15A/+); also elsewhere on the board
/lED2: U201.A4 (PT6B/-); also elsewhere on the board
/lED3: U201.B4 (PT11B/-); also elsewhere on the board
/lED4: U201.C4 (PT11A/+); also elsewhere on the board
/lED5: U201.A3 (PT6A/+); also elsewhere on the board
/lED6: U201.B3 (PT4B/-); also elsewhere on the board
/lED7: U201.A2 (PT4A/+); also elsewhere on the board
GND: C201.2, C202.2, C203.2, C204.2, C205.2, C206.2, C207.2, C208.2, C209.2, C210.2, C211.2, C212.2, C213.2, C214.2, C215.2, C216.2, C217.2, C218.2, C219.2, C220.2, C221.2, C222.2, C223.2, C224.2, C225.2, C226.2, C227.2, C228.2, C229.2, C230.2, C231.2, C232.2, C233.2, C234.2, J201.1, J201.3, J201.5, J201.7, J201.9, J201.11, J201.13, J201.15, J201.17, J201.19, J201.21, J201.23, J201.25, J201.27, J201.29, J201.31, J202.2, Q201.2 (S), R201.2, R204.1, R205.2, SW201.1, U201.A1 (GND[27]), U201.A16 (GND[27]), U201.D2 (GND[27]), U201.D15 (GND[27]), U201.F8 (GND[27]), U201.F9 (GND[27]), U201.G8 (GND[27]), U201.G10 (GND[27]), U201.H1 (GND[27]), U201.H8 (GND[27]), U201.H9 (GND[27]), U201.H10 (GND[27]), U201.H16 (GND[27]), U201.J8 (GND[27]), U201.J9 (GND[27]), U201.J10 (GND[27]), U201.K6 (GND[27]), U201.K7 (GND[27]), U201.K8 (GND[27]), U201.K9 (GND[27]), U201.K10 (GND[27]), U201.N2 (GND[27]), U201.N15 (GND[27]), U201.T1 (GND[27]), U201.T5 (GND[27]), U201.T12 (GND[27]), U201.T16 (GND[27]), U202.4 (GND), U202.9 (GND), U502.2 (GND), X201.2 (GND); also elsewhere on the board
unnamed: D201.2 (A), R212.1
unnamed: D201.1 (K), Q201.3 (D)
unnamed: R207.2, U201.R8 (PB13A/+/SN/CSN)
unnamed: C222.1, FB404.1, U502.1 (VDD)

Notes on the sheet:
CFG[2:0] = 010 Boot from SPI Flash
Bank 0 (Top right)
bottom side (sensible)
VCore
top side (experiment)
FLASH / CONFIG
JTAG
Bank 2 (Bottom right)
IO Banks
Bank 1 (Bottom right)
Bank 7 (Top right)
Button can be configured for DFU
Bank 3 (Bottom left)
Bank 6 (Left)

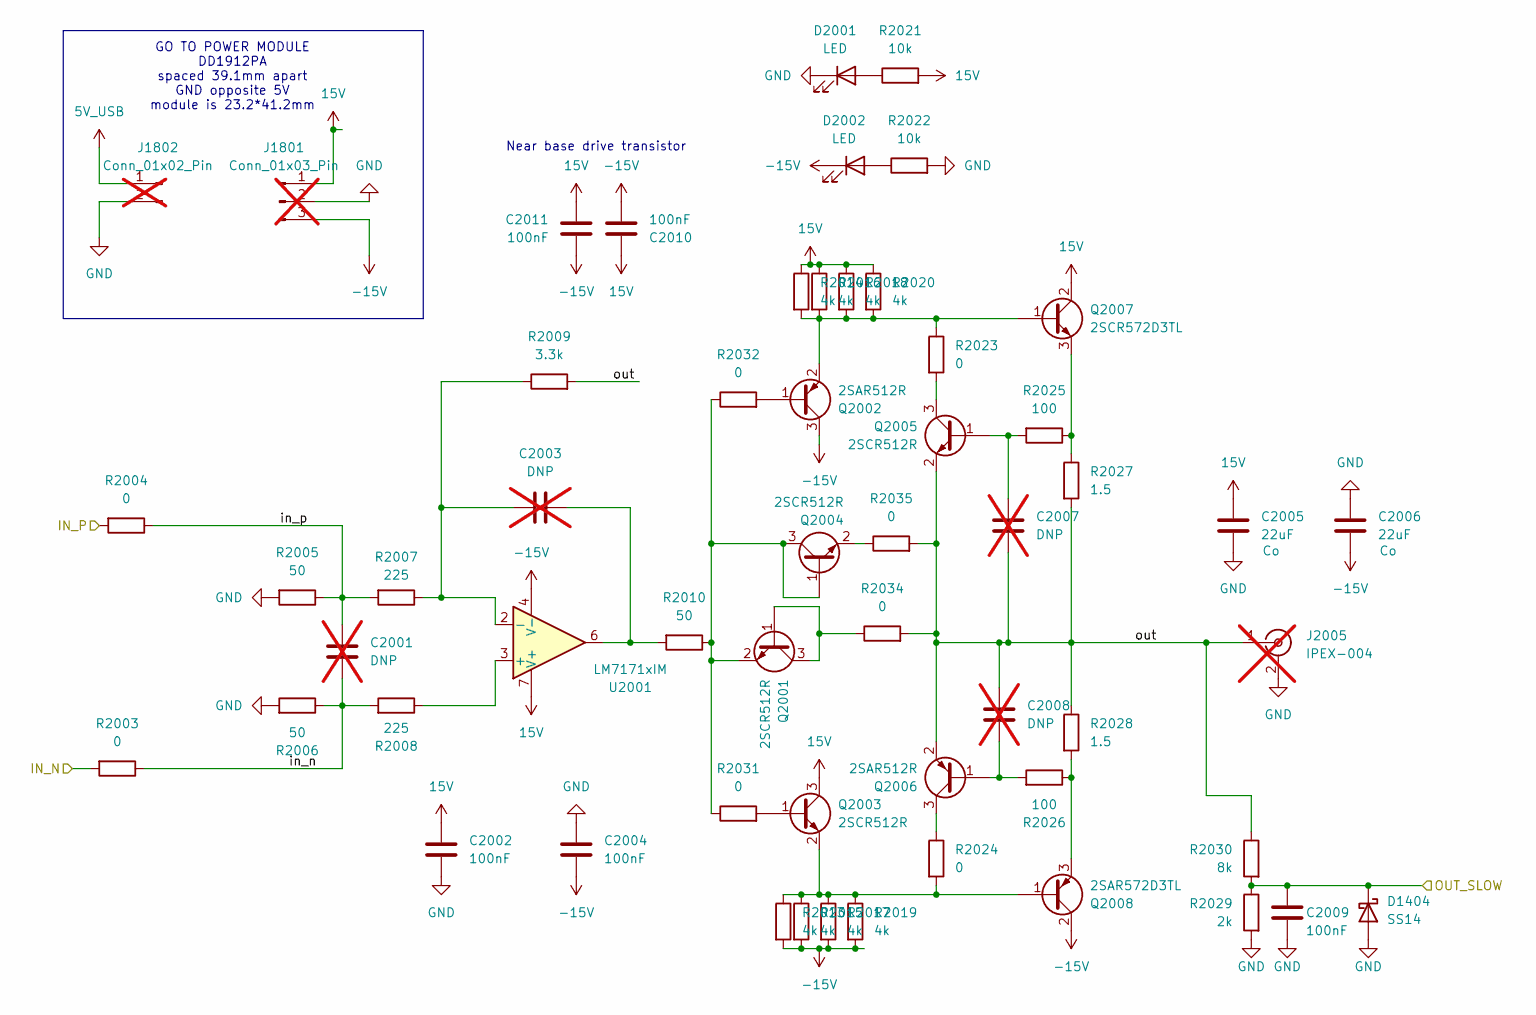
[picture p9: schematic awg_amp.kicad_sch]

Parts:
C2001: DNP; C_0603_1608Metric; LCSC C21120; not fitted
C2002, C2004, C2009, C2010, C2011: 100nF; C_0603_1608Metric; LCSC C1634
C2003, C2007, C2008: DNP; C_0603_1608Metric; LCSC C1634; not fitted
C2005, C2006: 22uF; C_1206_3216Metric
D1404: SS14; D_SMA
D2001, D2002: LED; D_0603_1608Metric; LCSC C2286
J1801: Conn_01x03_Pin; PinHeader_1x03_P2.54mm_Vertical; not fitted
J1802: Conn_01x02_Pin; PinHeader_1x02_P2.54mm_Vertical; not fitted
J2005: IPEX-004; SMA_Amphenol_132289_EdgeMount; not fitted
Q2001, Q2003, Q2004, Q2005: 2SCR512R; SOT-23
Q2002, Q2006: 2SAR512R; SOT-23
Q2007: 2SCR572D3TL; TO-252-2
Q2008: 2SAR572D3TL; TO-252-2
R2003, R2004, R2023, R2024, R2031, R2032, R2034, R2035: 0; R_0603_1608Metric; LCSC C21189
R2005, R2006, R2010: 50; R_0603_1608Metric; LCSC C23185
R2007, R2008: 225; R_0603_1608Metric; LCSC C22962
R2009: 3.3k; R_0603_1608Metric; LCSC C22975
R2013, R2014, R2015, R2016, R2017, R2018, R2019, R2020: 4k; R_0603_1608Metric; LCSC C23138
R2021, R2022: 10k; R_0603_1608Metric; LCSC C25804
R2025, R2026: 100; R_0603_1608Metric; LCSC C22775
R2027, R2028: 1.5; R_0603_1608Metric
R2029: 2k; R_0603_1608Metric
R2030: 8k; R_0603_1608Metric; LCSC C23138
U2001: LM7171xIM; SOIC-8_3.9x4.9mm_P1.27mm; LCSC C111821

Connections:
5V_USB: J1802.1; also elsewhere on the board
15V: C2002.1, C2005.1, C2010.1, C2011.1, J1801.1, Q2003.3 (C), Q2007.2 (C), R2014.1, R2016.1, R2018.1, R2020.1, R2021.2, U2001.7 (V+)
-15V: C2004.2, C2006.2, C2010.2, C2011.2, D2002.1 (K), J1801.3, Q2002.3 (C), Q2008.2 (C), R2013.2, R2015.2, R2017.2, R2019.2, U2001.4 (V-)
/AD9744/OUT_N: R2003.2; also elsewhere on the board
/AD9744/OUT_P: R2004.2; also elsewhere on the board
/awg_amp/OUT_SLOW: C2009.1, D1404.1 (K), R2029.1, R2030.2; also elsewhere on the board
/awg_amp/in_n: C2001.2, R2003.1, R2006.1, R2008.2
/awg_amp/in_p: C2001.1, R2004.1, R2005.1, R2007.2
/awg_amp/out: C2007.2, C2008.1, J2005.1 (In), Q2005.2 (E), Q2006.2 (E), R2009.2, R2027.2, R2028.1, R2030.1, R2034.2, R2035.2
GND: C2002.2, C2004.1, C2005.2, C2006.1, C2009.2, D1404.2 (A), D2001.1 (K), J1801.2, J1802.2, J2005.2 (Ext), R2005.2, R2006.2, R2022.2, R2029.2; also elsewhere on the board
unnamed: C2003.1, R2010.2, U2001.6
unnamed: D2001.2 (A), R2021.1
unnamed: D2002.2 (A), R2022.1
unnamed: Q2001.1 (B), Q2001.3 (C), R2034.1
unnamed: Q2001.2 (E), Q2004.1 (B), Q2004.3 (C), R2010.1, R2031.1, R2032.1
unnamed: Q2002.1 (B), R2032.2
unnamed: Q2002.2 (E), Q2007.1 (B), R2014.2, R2016.2, R2018.2, R2020.2, R2023.1
unnamed: Q2003.1 (B), R2031.2
unnamed: Q2003.2 (E), Q2008.1 (B), R2013.1, R2015.1, R2017.1, R2019.1, R2024.2
unnamed: Q2004.2 (E), R2035.1
unnamed: C2007.1, Q2005.1 (B), R2025.2
unnamed: Q2005.3 (C), R2023.2
unnamed: C2008.2, Q2006.1 (B), R2026.2
unnamed: Q2006.3 (C), R2024.1
unnamed: Q2007.3 (E), R2025.1, R2027.1
unnamed: Q2008.3 (E), R2026.1, R2028.2
unnamed: R2008.1, U2001.3 (+)
unnamed: C2003.2, R2007.1, R2009.1, U2001.2 (-)

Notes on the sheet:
GO TO POWER MODULE DD1912PA spaced 39.1mm apart GND opposite 5V module is 23.2*41.2mm
Near base drive transistor

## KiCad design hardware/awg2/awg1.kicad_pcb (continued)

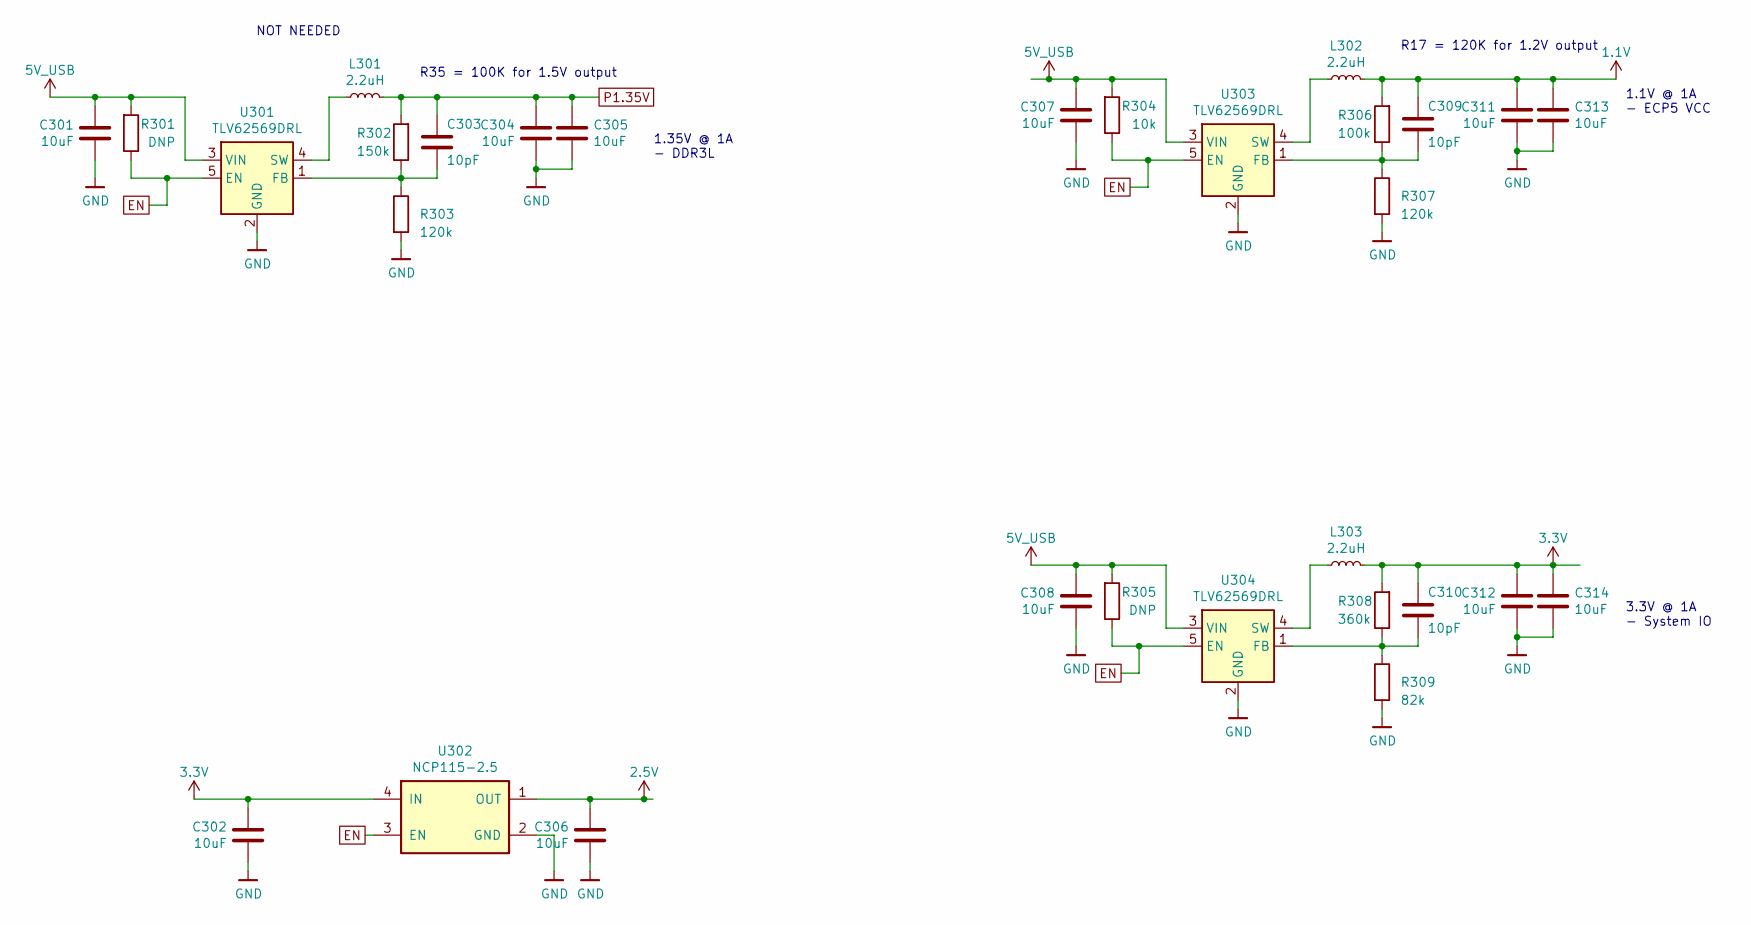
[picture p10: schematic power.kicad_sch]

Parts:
C301, C302, C304, C305, C306, C307, C308, C311, C312, C313, C314: 10uF; C_0603_1608Metric
C303, C309, C310: 10pF; C_0603_1608Metric
L301, L302, L303: 2.2uH; L_0805_2012Metric
R301, R305: DNP; C_0603_1608Metric
R302: 150k; C_0603_1608Metric
R303, R307: 120k; C_0603_1608Metric
R304: 10k; C_0603_1608Metric
R306: 100k; C_0603_1608Metric
R308: 360k; C_0603_1608Metric
R309: 82k; C_0603_1608Metric
U301, U303, U304: TLV62569DRL; SOT-563
U302: NCP115-2.5; Texas_X2SON-4_1x1mm_P0.65mm

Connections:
1.1V: C309.2, C311.2, C313.2, L302.2, R306.2; also elsewhere on the board
2.5V: C306.2, U302.1 (OUT); also elsewhere on the board
3.3V: C302.2, C310.2, C312.2, C314.2, L303.2, R308.2, U302.4 (IN); also elsewhere on the board
5V_USB: C301.2, C307.2, C308.2, R301.2, R304.2, R305.2, U301.3 (VIN), U303.3 (VIN), U304.3 (VIN); also elsewhere on the board
EN: R301.1, R304.1, R305.1, U301.5 (EN), U302.3 (EN), U303.5 (EN), U304.5 (EN)
GND: C301.1, C302.1, C304.1, C305.1, C306.1, C307.1, C308.1, C311.1, C312.1, C313.1, C314.1, R303.2, R307.2, R309.2, U301.2 (GND), U302.2 (GND), U303.2 (GND), U304.2 (GND); also elsewhere on the board
unnamed: C303.1, R302.1, R303.1, U301.1 (FB)
unnamed: C303.2, C304.2, C305.2, L301.2, R302.2
unnamed: L301.1, U301.4 (SW)
unnamed: C309.1, R306.1, R307.1, U303.1 (FB)
unnamed: L302.1, U303.4 (SW)
unnamed: C310.1, R308.1, R309.1, U304.1 (FB)
unnamed: L303.1, U304.4 (SW)

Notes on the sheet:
1.1V @ 1A - ECP5 VCC
1.35V @ 1A - DDR3L
3.3V @ 1A - System IO
R35 = 100K for 1.5V output
R17 = 120K for 1.2V output
NOT NEEDED

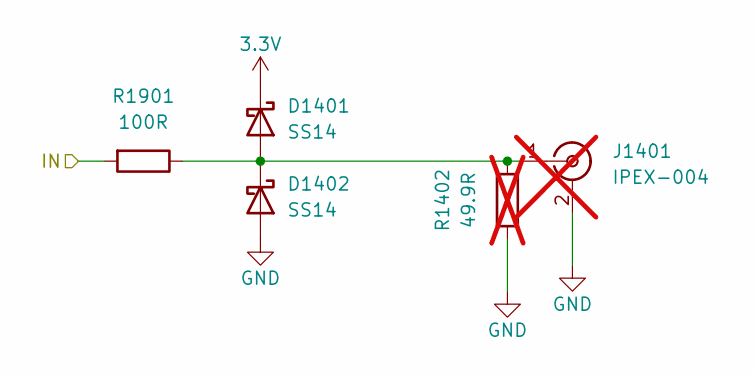
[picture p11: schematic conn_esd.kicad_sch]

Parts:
D1401, D1402: SS14; D_SMA
J1401: IPEX-004; SMA_Amphenol_132289_EdgeMount; not fitted
R1402: 49.9R; R_0603_1608Metric; not fitted
R1901: 100R; R_0603_1608Metric

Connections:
3.3V: D1401.1 (K); also elsewhere on the board
/fpga/DOUT1: R1901.2; also elsewhere on the board
GND: D1402.2 (A), J1401.2 (Ext), R1402.1; also elsewhere on the board
unnamed: D1401.2 (A), D1402.1 (K), J1401.1 (In), R1402.2, R1901.1

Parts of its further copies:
D1501, D1502, D1601, D1602, D1701, D1702: SS14; D_SMA
J1501, J1601, J1701: IPEX-004; SMA_Amphenol_132289_EdgeMount; not fitted
R1502, R1602, R1702: 49.9R; R_0603_1608Metric; not fitted
R1903, R1904, R1905: 100R; R_0603_1608Metric

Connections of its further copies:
3.3V: D1501.1 (K), D1601.1 (K), D1701.1 (K); also elsewhere on the board
/fpga/DOUT0: R1905.2; also elsewhere on the board
/fpga/REFCLK: R1904.2; also elsewhere on the board
/fpga/TRIG: R1903.2; also elsewhere on the board
GND: D1502.2 (A), D1602.2 (A), D1702.2 (A), J1501.2 (Ext), J1601.2 (Ext), J1701.2 (Ext), R1502.1, R1602.1, R1702.1; also elsewhere on the board
unnamed: D1501.2 (A), D1502.1 (K), J1501.1 (In), R1502.2, R1903.1
unnamed: D1601.2 (A), D1602.1 (K), J1601.1 (In), R1602.2, R1904.1
unnamed: D1701.2 (A), D1702.1 (K), J1701.1 (In), R1702.2, R1905.1

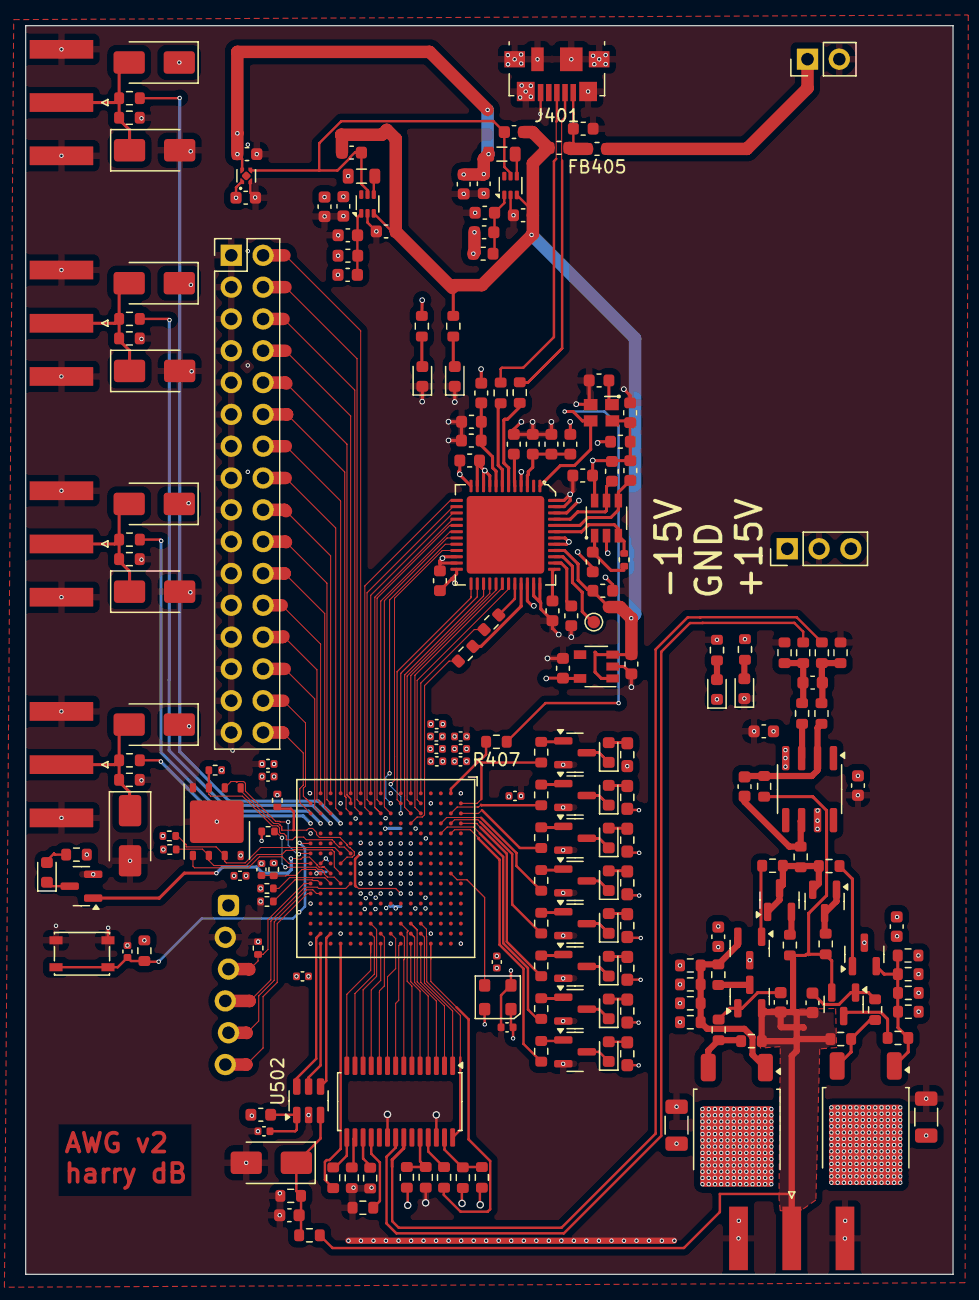
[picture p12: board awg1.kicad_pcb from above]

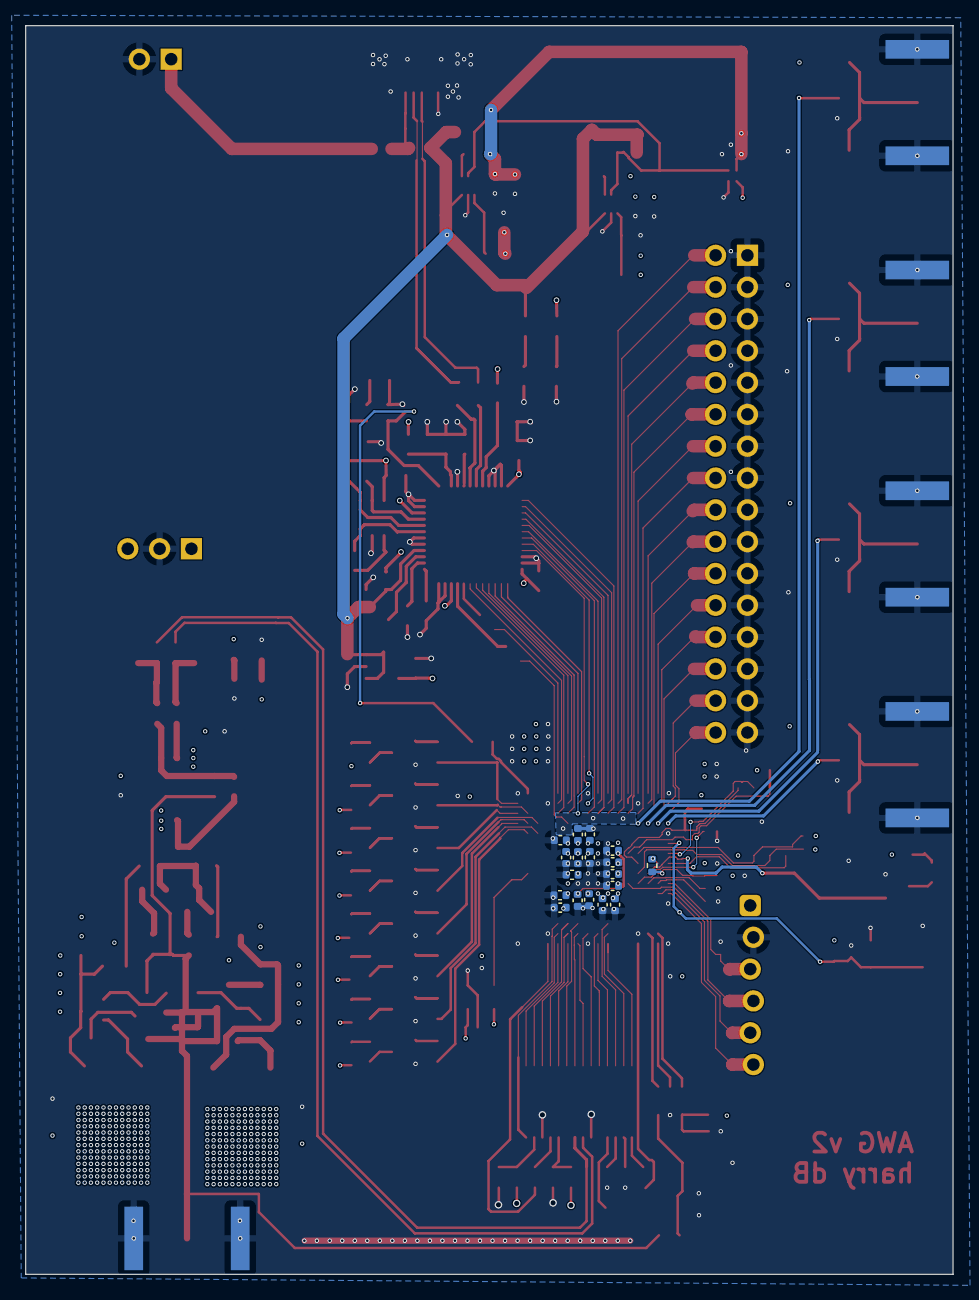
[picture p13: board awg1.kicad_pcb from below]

Board: 6 copper layers, 74.0 x 99.7 mm, 235 parts (18 on the bottom side), 180 nets.

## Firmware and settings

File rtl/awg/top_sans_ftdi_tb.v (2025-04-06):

`timescale 1ns/1ps

`default_nettype none
`include "defines.v"
`include "test_data.gen.v"

`timescale 1ns/1ps

module sequential_tb;
    reg start_streaming = 0;
    reg start_trigger = 0;
    reg end_signal = 0;

    // Instantiate both test modules
    streaming_tb stream_test();
    trigger_tb trig_test();

    // Main test sequencer
    initial begin
        $display("\n==================================== Starting Streaming Mode Test ====================================");
        start_streaming = 1;
        #10000;  // Your original delay
        
        $display("\n==================================== Starting Trigger Mode Test ====================================");
        start_streaming = 0;
        start_trigger = 1;
        #10000;  // Your original delay
        
        end_signal = 1;
        $display("\n=== All Tests Completed ===");
        $finish;
    end

endmodule

module streaming_tb;
    initial begin
        wait(sequential_tb.start_streaming);
    end

    reg clk100;
    reg fsm_tvalid = 0;
    wire fsm_tready;
    reg [7:0] fsm_tdata;
    reg trigger = 1'b1;
    wire [`BIT_WIDTH - 1:0] awg_out;
    wire awg_valid;
    wire awg_clk;
    wire err_latched;

    top_sans_ftdi #(
        .BIT_WIDTH(`BIT_WIDTH)
        ) uut (
        .clk100         ( clk100 ),
        .fsm_tvalid     ( fsm_tvalid ),
        .fsm_tready     ( fsm_tready ),
        .fsm_tdata        ( fsm_tdata ),
        .trigger       ( trigger ),
        .awg_out        ( awg_out ),
        .awg_clk       ( awg_clk ),
        .awg_valid     ( awg_valid ),
        .err_latched    ( err_latched ),
        .logic_out     (  )
    );

    initial begin
        $dumpfile("streaming_tb.vcd");
        $dumpvars(0, streaming_tb);
        $display("%d",  uut.BIT_WIDTH);

        clk100 = 0;
        forever #5 clk100 = (~clk100 & sequential_tb.start_streaming); // 100 MHz clock -> period of 10 ns
    end

    initial begin
        $display("Testing streaming mode");
        #10000;
        // #1000;
        $display("Streaming mode ended.");
        // $display("############FINISHED############\n\n");
        // $finish;
    end

    test_vector_TRIGGER_MODE_NONE td();

    // Running of the test.
    integer cooldown_counter = 0;
    integer data_index = 0;
    reg [8*22-1:0] tb_state = "UNINITIALIZED";
    initial begin
        fsm_tdata <= td.byte_stream[data_index];
        fsm_tvalid <= 1;
        data_index = 1;
        tb_state <= "Begin transmission";
        forever begin
            @(posedge clk100);
            // Loop through the state machine twice:

            if (fsm_tready && data_index < td.NUM_TEST_BYTES) begin
                fsm_tdata <= td.byte_stream[data_index];
                data_index <= data_index + 1;
                tb_state <= "Transmitting data";
            end

            if (data_index == td.NUM_TEST_BYTES) begin
                tb_state <= "cooldown";
                cooldown_counter = cooldown_counter + 1;
            end

            if (fsm_tready && data_index == td.NUM_TEST_BYTES && cooldown_counter > 1) begin
                fsm_tvalid <= 0;
                $display("added delays");
                #800
                fsm_tvalid <= 1;
                data_index = 0;
            end


        end
    end

    // Checking the output.
    reg [`BIT_WIDTH - 1:0] waveform_out[0:999];
    integer wf_idx = 0;
    reg[`BIT_WIDTH - 1:0] expected_wf = 0;
    initial begin
        $display("td.NUM_TEST_SAMPLES = %0d", td.NUM_TEST_SAMPLES);
        // forever begin @(posedge clk100);
        forever begin @(posedge awg_clk);
            waveform_out[wf_idx] <= awg_out;
            wf_idx <= wf_idx + 1;
            $display("storing waveform_out[%0d] = %b", wf_idx, awg_out);
            if (wf_idx == td.NUM_TEST_SAMPLES - 1) begin
                // check all the waveform samples:
                $display("Checking waveform samples");
                for (integer w_idx = 0; w_idx < td.NUM_TEST_SAMPLES; w_idx = w_idx + 1) begin
                    $display("waveform_out[%0d] = %b", w_idx, waveform_out[w_idx]);
                    expected_wf = td.sample_stream[w_idx];
                    if (waveform_out[w_idx] != expected_wf) begin
                        $error("waveform_out[%0d] = %b, expected %b", w_idx, waveform_out[w_idx], expected_wf);
                    end
                end
                wf_idx <= 0;
            end
        end
    end
    initial begin
        forever begin @(posedge err_latched);
            $display("Error latched");
        end
    end
endmodule



module trigger_tb;
    initial begin
        wait(sequential_tb.start_trigger);
    end

    reg clk100;
    reg fsm_tvalid = 0;
    wire fsm_tready;
    reg [7:0] fsm_tdata;
    wire [`BIT_WIDTH - 1:0] awg_out;
    wire awg_clk;
    wire awg_valid;
    wire err_latched;

    localparam TRIGGER_INTERVAL = 150;
    integer trigger_counter = (TRIGGER_INTERVAL * 7) / 10;
    // wire trigger = trigger_counter >= TRIGGER_INTERVAL - 5;
    wire trigger = trigger_counter == TRIGGER_INTERVAL;

    top_sans_ftdi #(
        .BIT_WIDTH(`BIT_WIDTH)
        ) uut (
        .clk100         ( clk100 ),
        .fsm_tvalid     ( fsm_tvalid ),
        .fsm_tready     ( fsm_tready ),
        .fsm_tdata        ( fsm_tdata ),
        .trigger       ( trigger ),
        .awg_out        ( awg_out ),
        .awg_clk       ( awg_clk ),
        .awg_valid     ( awg_valid ),
        .err_latched    ( err_latched ),
        .logic_out     (  )
    );

    initial begin
        // wait(sequential_tb.start_trigger);
        $display("BIT_WIDTH = %0d", `BIT_WIDTH);
        // $dumpfile("trigger_tb.vcd");
        $dumpvars(0, trigger_tb);

        clk100 = 0;
        forever #5 clk100 = ~clk100; // 100 MHz clock -> period of 10 ns
    end

    initial begin
        // wait(sequential_tb.start_trigger);
        $display("Testing trigger mode");
        #10000;
        $display("Trigger mode ended.");
        // $finish;
    end

    test_vector_TRIGGER_MODE_EDGE td();


    // Running of the test.
    integer data_index = 0;
    integer num_triggers = 0;
    reg [8*22-1:0] tb_state = "UNINITIALIZED";
    initial begin
        wait(sequential_tb.start_trigger);
        fsm_tdata <= td.byte_stream[data_index];
        fsm_tvalid <= 1;
        data_index = 1;
        tb_state <= "Begin transmission";

        forever begin
            @(posedge clk100);
            // Loop through the state machine twice:

            if (fsm_tready && data_index < td.NUM_TEST_BYTES) begin
                fsm_tdata <= td.byte_stream[data_index];
                data_index <= (data_index + 1) % td.NUM_TEST_BYTES;
                tb_state <= "Transmitting data";
            end
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

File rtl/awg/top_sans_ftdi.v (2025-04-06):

`default_nettype none
`timescale 1ns/1ps

module top_sans_ftdi # (
    parameter BIT_WIDTH = 8
) (
    input  wire         clk100,

    input  wire         fsm_tvalid,
    output  wire         fsm_tready,
    input  wire [7:0]   fsm_tdata,

    input wire trigger,

    output wire [BIT_WIDTH - 1:0]   awg_out,
    output wire awg_clk,
    output wire         awg_valid,

    output wire err_latched,

    // output reg [BIT_WIDTH - 1:0] logic_out,
    output wire [15:0] logic_out
);

    wire fsm_to_awg_ready;
    wire fsm_to_awg_valid;
    wire [BIT_WIDTH - 1:0] fsm_to_awg_data;
    wire [6:0] trigger_mode;
    wire [7:0] fsm_dbg;

    state_machine #(
        .BW_OUT(BIT_WIDTH),
        .BW_IN(8)
    ) fsm_inst (
        .clk100         ( clk100         ),
        .in_tvalid      ( fsm_tvalid     ),
        .in_tready      ( fsm_tready     ),
        .in_tdata       ( fsm_tdata      ),
        .awg_valid      ( fsm_to_awg_valid ),
        .awg_ready      ( fsm_to_awg_ready ),
        .awg_out        ( fsm_to_awg_data ),
        .trigger_mode   ( trigger_mode   ),
        .err_latched    ( err_latched    ),
        .dbg            ( fsm_dbg        )
    );

    wire trig_out;

    // Instantiate awg Interface
    awg_output #(
        .BIT_WIDTH(BIT_WIDTH)
    ) awg_inst (
        .clk100         ( clk100         ),
        .in_tvalid      ( fsm_to_awg_valid ),
        .in_tready      ( fsm_to_awg_ready ),
        .in_tdata       ( fsm_to_awg_data  ),
        .trigger        ( trig_out       ),
        .awg_valid      ( awg_valid      ),
        .clkout         ( awg_clk        ),
        .awg_out        ( awg_out        )
    );

    wire [7:0] trigger_mode_dbg;
    trigger_mode trigger_inst (
        .clk100     ( clk100 ),
        .cmd        ( trigger_mode ),
        .trig_in    ( trigger ),
        .trig_out   ( trig_out),
        .debug  ( trigger_mode_dbg )
    );
    // assign logic_out = 16'hffff;

    // assign logic_out[8] = fsm_tvalid;
    // assign logic_out[9] = fsm_tready;
    // assign logic_out[10] = fsm_to_awg_valid;
    // assign logic_out[11] = fsm_to_awg_ready;
    // assign logic_out[12] = fsm_to_awg_data[0];
    // assign logic_out[13] = trig_out;
    // assign logic_out[14] = trigger_mode_dbg[2];
    // assign logic_out[15] = trigger_mode_dbg[1];

    // assign logic_out[7] = trigger;
    // assign logic_out[6] = trig_out;
    assign logic_out[7:0] = trigger_mode_dbg;
    // assign logic_out[2:0] = 2'b11;
    // assign logic_out[7:0] = fsm_dbg;


endmodule

module trigger_mode (

    input wire clk100,
    input wire[6:0] cmd,
    input wire trig_in,
    output reg trig_out = 1'b1,
    output wire [7:0] debug
);
    `ifdef TESTBENCH reg [8*22-1:0] state_name = "INIT"; `endif

    localparam [2:0] UNTRIGGERABLE = 3'b100;
    localparam [2:0] TRIGGERED = 3'b110;
    localparam [2:0] EDGE_IDLE = 3'b001;
    localparam [2:0] EDGE_TRIGD = 3'b010;
    localparam [2:0] GATED = 3'b011;
    reg [2:0] state = TRIGGERED;


    reg trig_latched = 1'b1;
    reg trig_in_del = 1'b0;
    // assign trig_edge = trig_in & ~trig_in_del;
    reg trig_edge = 1'b0;

    assign debug[2:0] = state;
    assign debug[3] = trig_in;
    assign debug[4] = trig_in_del;
    assign debug[5] = trig_edge;
    assign debug[6] = clk100;


    always @(posedge clk100) begin
        trig_latched <= trig_in;
        trig_edge <= trig_latched & ~trig_in_del;
        trig_in_del <= trig_latched;

        if (cmd == `TRIGGER_MODE_NONE) begin
            `ifdef TESTBENCH state_name <= "UNTRIGGERABLE"; `endif
            trig_out <= 1'b1;
            state <= TRIGGERED;

        end else if (cmd == `TRIGGER_MODE_EDGE) begin
            if (state != EDGE_IDLE && state != EDGE_TRIGD) begin
                `ifdef TESTBENCH state_name <= "EDGE_IDLE"; `endif
                state <= EDGE_IDLE;
                trig_out <= 1'b0;
            end else begin
                if (trig_edge) begin
                    `ifdef TESTBENCH state_name <= "EDGE_TRIGD"; `endif
                    trig_out <= 1'b1;
                    state <= EDGE_TRIGD;
                end else begin
                    `ifdef TESTBENCH state_name <= "~EDGE_TRIGD"; `endif
                end
            end
        end else if (cmd == `RESET_EDGE) begin
            `ifdef TESTBENCH state_name <= "RESET_EDGE"; `endif
            if (state == EDGE_TRIGD) begin
                trig_out <= 1'b0;
                state <= EDGE_IDLE;
            
            // If we didn't transition from EDGE_IDLE to TRIGGERED here, we would
            // never read in another byte and hence deadlock. So go to TRIGGERED
            // so we can proceed.
            end else if (state == EDGE_IDLE) begin
                if (trig_in) begin
                    trig_out <= 1'b1;
                    state <= TRIGGERED;
                end
                
            end

        // end else if (cmd == `TRIGGER_MODE_GATE) begin
        //     `ifdef TESTBENCH state_name <= "GATED"; `endif
        //     state <= GATED;
        //     trig_out <= trig_in;
        end
    end
endmodule

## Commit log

2025-04-06 add in the things
    [AD9744.kicad_sch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]
2025-05-17 fix ftdi C eeprom programming, and change vid and pid so that the linux triveer doesn't grab it
2025-05-17 fix misc bugs and make the package installable
    [awg_output.v]
